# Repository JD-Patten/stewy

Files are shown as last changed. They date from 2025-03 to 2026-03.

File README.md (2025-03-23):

# Stewy

Stewy is a Stewart platform designed as an educational tool. It is capable of moving its top plate around with 6 degrees of freedom and using its arms to lift its base for walking around.

Currently, the code in this repository is working, but needs to be cleaned up and better documented. These improvements will be completed by the end of Stewy's Kickstarter campaign. Please check the kickstarter page [here](https://www.kickstarter.com/projects/jdrobotics/stewy-learn-robotics-with-this-open-source-platform) for an overview and updates on the project.

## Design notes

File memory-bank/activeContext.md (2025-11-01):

# Active Context: Stewy

## Current Work Focus

### Primary Goal: Polish and Expand Core Features
With core motion, communication, and sensor integration complete, focus on refinement, documentation, and advanced behaviors. Collision avoidance is now fully operational, marking a major milestone.

## Recent Changes

### Collision Avoidance Implementation ✅
- **What Changed**: Added _collisionOffsetMagnitude scalar ramping on distance <5cm, _collisionOffsets Pose for translation (+X cos20°, -Z sin20° body-frame)
- **Integration**: Sums with _integratedOffsets in update(), resets on trajectories, _currentPose synced to offsetted pose
- **User Tweaks**: Fixed 150mm target, +X flip for sensor orientation, 5cm threshold (cm units)
- **Files Modified**: controller.h/cpp (members, updateSensorState(), update())
- **Tested**: Triggering, ramping, joystick compatibility, pose adjustment
- **Pattern**: Velocity-based accumulation like joystick, modular Pose summing

### Joystick Pose Control Completion ✅
- **What Changed**: Full JOYSTICK_X/Y/Z modes with DOF mapping, IK-validated _integratedOffsets (Pose)
- **Features**: Velocity deltas, mode-specific trans/rot pairs, reset on trajectory
- **Files Modified**: controller.cpp (updateSensorState())
- **Tested**: Axis control, validation skips invalid, smooth nudging

### Communication Refactoring ✅
- **

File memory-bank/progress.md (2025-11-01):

# Progress: Stewy

## What Works ✅

### Core Functionality (Fully Operational)

#### 1. Inverse Kinematics System
- **Status**: Production-ready
- **Capabilities**:
  - Converts any valid 6-DOF pose to servo angles
  - Validates solutions before returning
  - Handles error conditions gracefully
  - Precomputed geometry for efficiency
- **Tested**: Extensively, handles edge cases
- **Performance**: <1ms solve time

#### 2. Trajectory Planning & Control
- **Status**: Production-ready
- **Capabilities**:
  - Smooth motion between poses using 3rd order polynomials
  - Respects acceleration limits (translation & rotation)
  - Continuous trajectory evaluation
  - Automatic duration minimization
- **Tested**: Various poses, speeds, accelerations
- **Reference**: Based on Modern Robotics textbook

#### 3. Walking Pattern (Forward/Left/Right)
- **Status**: Production-ready
- **Capabilities**:
  - Genetic algorithm-optimized gait
  - Three directions: forward, left, right (left is more backwards left and right more backwards right)
  - Variable speed control
  - Smooth transitions (fade-in, mirroring)
  - Adjustable speed multiplier
- **Tested**: All directions, various speeds
- **Known Limitation**: No true backward (use negative speed)
- **Recent Fix**: Direction inversion corrected by negating speed parameter (genetic algorithm pattern inherently moves backward)

#### 4. Communication Layer
- **Status**: Production-ready
- **Capabilities**:
  - WiFi Access Point (no internet needed)
  - HTTP REST API for commands
  - UDP server for real-time sensor data
  - mDNS for easy connection (robot.local)
  - Callback-based architecture
- **Tested**: Web control, UDP packets from head
- **Reliability**: Stable, handles packet loss

#### 5. Web Interface
- **Status**: Production-ready
- **Capabilities**:
  - Pose control with 6-DOF input
  - Walking control (3 directions + speed)
  - Servo offset calibration
  - Acceleration limit tuning
  - Three-view toggle (control/settings/poses)
  - Mobile-responsive
- **Tested**: Multiple devices, browsers
- **Build Process**: Python script combines HTML/CSS/JS

#### 6. Servo Management
- **Status**: Production-ready
- **Capabilities**:
  - 6 independent PWM channels
  - Angle offset calibration per servo
  - Software angle limits (±80°)
  - Proper sign convention for mirrored servos
  - Interpolation to reduce jitter
- **Tested**: All servos, full range of motion
- **Calibration**: Per-robot tuning supported

#### 7. Joystick Pose Control
- **Status**: Fully implemented
- **Capabilities**:
  - JOYSTICK_X/Y/Z modes for translation/rotation DOFs
  - Velocity-based accumulation in _integratedOffsets (Pose)
  - IK validation before committing offsets
  - Sums with goal pose for physical movement
  - Mode cycling via button click
- **Tested**: Axis mapping, validation, offset application
- **Integration**: Works with collision avoidance offsets

#### 8. Collision Avoidance
- **Status**: Fully implemented and tested
- **Capabilities**:
  - Scalar magnitude (_collisionOffsetMagnitude) ramps at 50mm/s when distance <5cm (fixed 150mm target)
  - Pose offset (_collisionOffsets) as translation: magnitude * cos20° in +X, -magnitude * sin20° in Z (body-frame, zero rotation)
  - Sums with joystick offsets in update()
  - Resets on new trajectories
  - Current pose updated to include offsets for sync
- **Tested**: Triggering, ramping, pose adjustment, compatibility with joystick
- **User Adjustments**: Threshold to 5cm (sensor in cm), +X flip for sensor facing -X, fixed target (from linear)

## What's Left to Build 🚧

### High Priority (Current Sprint)

#### 1. Head Firmware Integration
- **Status**: 50% complete (exists but not in repo)
- **What Works**:
  - Head firmware functional on ESP32-C3
  - Reads distance and joystick
  - Sends UDP packets
- **What's Missing**:
  - Add to this repository
  - Documentation
  - Pin assignment diagram
  - Calibration instructions
- **Complexity**: Low (mostly documentation)
- **Estimate**: 2-3 days

### Medium Priority (Next Sprint)

#### 2. Code Documentation & Cleanup
- **Status**: 40% complete
- **What Exists**:
  - Function comments in key areas
  - Basic README
  - Memory bank documentation
- **What's Needed**:
  - Comprehensive inline comments
  - API documentation
  - Build/setup guide
  - Troubleshooting guide
  - Example code/tutorials
- **Complexity**: Low but time-consuming
- **Estimate**: 2 weeks

#### 3. Configuration Persistence
- **Status**: 0% complete (not started)
- **Requirements**:
  - Save servo offsets to EEPROM/NVS
  - Save acceleration limits
  - Save joystick calibration
  - Load on startup
- **Complexity**: Low
- **Estimate**: 3-4 days
- **Value**: High (no recalibration needed)

#### 4. OTA Firmware Updates
- **Status**: 0% complete (not started)
- **Requirements**:
  - Web-based firmware upload
  - Safe bootloader fallback
  - Version management
- **Complexity**: Medium-High
- **Estimate**: 1-2 weeks
- **Value**: High for users

### Low Priority (Future Enhancements)

#### 5. Additional Walking Patterns
- **Status**: Framework exists, no additional patterns
- **Ideas**:
  - Side-stepping gait
  - Rotating in place
  - Backward walking (true, not reversed forward)
  - Climbing gait
- **Complexity**: Medium (optimization needed)
- **Estimate**: 1 week per pattern
- **Value**: Medium (nice-to-have)

#### 6. Advanced Behaviors
- **Status**: 0% complete (conceptual)
- **Ideas**:
  - Object tracking (using distance sensor)
  - Dance sequences
  - Balancing challenges
  - Interactive games
- **Complexity**: High
- **Estimate**: Variable
- **Value**: High for engagement

#### 7. Mobile App
- **Status**: 0% complete (not planned yet)
- **Alternative**: Current web interface works on mobile
- **Potential Features**:
  - Better joystick emulation
  - Gesture control
  - Saved pose sequences
  - Robot status display
- **Complexity**: High
- **Estimate**: 4-6 weeks
- **Value**: Medium

## Current Status Summary

### Overall Project Completion: ~85%

**Core Platform**: 100% ✅
- Kinematics

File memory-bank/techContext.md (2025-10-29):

# Technical Context: Stewy

## Technology Stack

### Hardware Platform

#### Body Microcontroller
- **Model**: Waveshare ESP32-S3-Nano
- **Processor**: Dual-core Xtensa LX7 @ 240MHz
- **RAM**: 512KB SRAM
- **Flash**: 8MB
- **WiFi**: 802.11 b/g/n (2.4 GHz)
- **GPIO**: Sufficient for 6 PWM channels + peripherals

#### Head Microcontroller
- **Model**: ESP32-C3 Supermini
- **Processor**: RISC-V single-core @ 160MHz
- **RAM**: 400KB SRAM
- **Flash**: 4MB
- **WiFi**: 802.11 b/g/n (2.4 GHz)
- **Purpose**: Lightweight sensor reading and UDP transmission

#### Actuators
- **Type**: 9g metal gear servo motors
- **Quantity**: 6
- **Control**: PWM (50Hz standard)
- **Range**: 0-180° (software limited to ±80° from neutral)
- **Pins**: GPIO 3, 2, 1, 18, 17, 10 (body)

#### Sensors (Head)
- **HC-SR04 Ultrasonic Distance Sensor**
  - Range: 2cm - 400cm
  - Trigger/Echo pins on ESP32-C3
  - Purpose: Obstacle detection
  
- **KY-023 Dual-Axis Joystick**
  - 2x Analog outputs (ADC)
  - 1x Digital button
  - Center values: X=2160, Y=2200 (needs calibration)
  - Deadzone: ±25 units

### Software Stack

#### Development Framework
- **Core**: Arduino Framework
- **Platform**: PlatformIO or Arduino IDE
- **Language**: C++ (C++11 minimum)
- **Build System**: Arduino build chain

#### Key Libraries

##### ESP32Servo
- **Purpose**: PWM servo control on ESP32
- **Features**: 
  - Multiple timer allocation
  - Microsecond pulse width control
  - Configurable min/max pulse (500-2500μs)
- **Usage**: 
  ```cpp
  ESP32PWM::allocateTimer(0-3);  // Allocate 4 timers
  servo.setPeriodHertz(50);
  servo.attach(pin, 500, 2500);
  ```

##### ArduinoEigenDense
- **Purpose**: Linear algebra for IK calculations
- **Features**:
  - Matrix operations
  - Rotation matrices (AngleAxis)
  - Vector math
- **Size Impact**: ~50KB of flash
- **Performance**: Optimized for embedded
- **Usage**:
  ```cpp
  Matrix3d rotation = AngleAxisd(angle, Vector3d::UnitZ()).toRotationMatrix();
  Vector3d result = rotation * point;
  ```

##### WiFi (ESP32 Core)
- **Mode**: Access Point (softAP)
- **Features**:
  - DHCP server built-in
  - WPA2 security
  - No internet connectivity needed
- **Configuration**:
  ```cpp
  WiFi.softAP(ssid, password);
  IPAddress ip = WiFi.softAPIP();
  ```

##### WebServer (ESP32 Core)
- **Purpose**: HTTP REST API
- **Features**:
  - Route handling
  - GET parameter parsing
  - Static content serving
- **Limitations**: Single-threaded, blocking

##### WiFiUDP (ESP32 Core)
- **Purpose**: Real-time sensor data
- **Port**: 4210
- **Packet Size**: 6 bytes (JoystickPacket struct)
- **Performance**: ~10-50ms latency

##### ESPmDNS (ESP32 Core)
- **Purpose**: DNS-SD for easier connection
- **Hostname**: `robot.local`
- **Benefit**: Users don't need to remember IP address

### File Organization

```
stewy/
├── stewy.ino                    # Main entry point
├── controller.h / .cpp          # Motion control
├── inverse_kinematics.h / .cpp  # IK solver
├── walking_pattern.h / .cpp     # Gait generation
├── communication.h / .cpp       # WiFi/HTTP/UDP
├── user_interface.h             # Embedded HTML/CSS/JS
├── README.md                    # Project overview
├── LICENSE                      # Open source license
├── custom_instructions.clinerules # Cline memory bank config
├── CAD/                         # 3D printable parts
│   ├── Stewy Arm Left.step
│   ├── Stewy Arm Right.step
│   ├── Stewy Base Bottom.step
│   ├── Stewy Base top.step
│   └── Stewy Top Plate.step
├── web_interface/               # Web UI development
│   ├── index.html
│   ├── styles.css
│   ├── script.js
│   └── combine.py              # Build tool for user_interface.h
└── memory-bank/                # Cline context (this documentation)
    ├── projectbrief.md
    ├── productContext.md
    ├── systemPatterns.md
    ├── techContext.md
    ├── activeContext.md
    └── progress.md
```

## Development Setup

### Required Tools
1. **Arduino IDE** (v2.0+) OR **PlatformIO** (recommended)
2. **USB Cable** (USB-C for ESP32-S3-Nano)
3. **Serial Monitor** (for debugging)
4. **Python 3** (for web interface build script)

### Board Setup (Arduino IDE)
1. Install ESP32 board package:
   - URL: `https://raw.githubusercontent.com/espressif/arduino-esp32/gh-pages/package_esp32_index.json`
2. Select Board: "ESP32S3 Dev Module" (for body)
3. Select Port: Appropriate COM/tty port

### Library Installation
```
Required Libraries (Arduino Library Manager):
- ESP32Servo (by Kevin Harrington)
- ArduinoEigen (search "Eigen")

Built-in (no install needed):
- WiFi
- WebServer
- WiFiUDP
- ESPmDNS
```

### Build Process

#### For Body Firmware
1. Open `stewy.ino` in IDE
2. Select ESP32-S3 board
3. Compile and upload
4. Monitor serial output for IP address

#### For Web Interface
```bash
cd web_interface/
python combine.py
# This generates user_interface.h from index.html, styles.css, script.js
```

### Debugging Workflow

#### Serial Debugging
```cpp
Serial.begin(115200);
Serial.println("Debug message");
Serial.print("Value: "); Serial.println(value);
```

#### WiFi Connection Testing
1. Connect device to "stewyAP" (password: stewy123)
2. Navigate to `http://192.168.4.1` or `http://robot.local`
3. Check browser console for JavaScript errors

#### Servo Calibration
1. Set all offsets to 0
2. Command neutral pose (0

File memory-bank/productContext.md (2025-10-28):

# Product Context: Stewy

## Why This Project Exists

### Problem Statement
Robotics education often faces barriers:
- **Expensive platforms**: Industrial-grade robots cost thousands
- **Oversimplified kits**: Many educational robots don't teach real robotics concepts
- **Complex theory**: Inverse kinematics and control systems seem inaccessible
- **Limited hands-on experience**: Students learn theory but struggle with implementation

### Solution: Stewy
An affordable, approachable platform that teaches real robotics without oversimplification. Users build, program, and experiment with a robot that uses the same mathematical foundations as industrial robots.

## How It Works

### Core Concept: Stewart Platform
A Stewart platform is a parallel robot with 6 legs connecting a base to a top plate. By controlling the leg lengths (via servo angles), the platform achieves 6-DOF motion. Stewy uses this mechanism both for pose control AND walking.

### User Experience Flow

#### 1. Assembly & Setup
- Users 3D print mechanical parts from provided CAD files
- Assemble with kit-provided electronics
- Flash firmware to ESP32 microcontrollers
- Connect to WiFi access point hosted by robot

#### 2. Initial Calibration
- Web interface provides servo offset adjustment
- Users tune each servo to achieve neutral pose
- Set acceleration limits for smooth motion

#### 3. Pose Control (Primary Mode)
- **Web Interface**: 6 input fields (x, y, z, roll, pitch, yaw)
- **Joystick Control** (planned): Physical joystick controls each axis
- Real-time trajectory planning creates smooth motion
- Visual feedback through robot movement

#### 4. Walking Mode
- Three-direction walking: forward, left, right
- Hexagon-shaped buttons on web interface
- Speed multiplier for variable walking speed
- Genetic algorithm-optimized gait pattern

#### 5. Autonomous Behavior (Planned)
- Distance sensor detects obstacles
- Robot retracts head and walks backward
- Demonstrates basic reactive behavior

### Control Modes
The robot cycles through 5 modes via joystick button click:
1. **STANDARD**: Web interface control only
2. **JOYSTICK_X**: Joystick controls X translation
3. **JOYSTICK_Y**: Joystick controls Y translation  
4. **JOYSTICK_Z**: Joystick controls Z (height)
5. **JOYSTICK_WALK**: Joystick controls walking direction/speed

## Educational Value

### Concepts Taught

#### Beginner Level
- Basic embedded programming (Arduino framework)
- Servo motor control
- WiFi communication
- Web interface development

#### Intermediate Level
- Inverse kinematics mathematics
- Coordinate frame transformations
- PID control and trajectory planning
- Sensor integration and filtering

#### Advanced Level
- Multi-variable optimization (walking pattern)
- Parallel mechanism analysis
- Real-time control systems
- Custom behavior development

### Learning Progression
1. **Week 1-2**: Assembly, basic pose control
2. **Week 3-4**: Understanding IK solver, experimenting with poses
3. **Week 5-6**: Walking patterns, gait analysis
4. **Week 7+**: Custom features, behavior programming

## User Interaction Design

### Web Interface
- **Simple and Clean**: Large buttons, clear labels
- **Three Views**:
  - Control view (pose/walking)
  - Settings view (offsets, accelerations)
  - Pose library (saved positions)
- **Real-time**: Immediate response to commands
- **Mobile-friendly**: Works on phones/tablets

### Physical Remote (Head)
- **Ergonomic**: Designed to be held in hand
- **Tactile Feedback**: Physical joystick for precise control
- **Dual Purpose**: Mounts on body or used as remote
- **Wireless**: No tethering during operation

## Success Criteria

### For Users
- Successfully build and calibrate robot
- Understand inverse kinematics fundamentals
- Create custom poses and walking sequences
- Extend with own code modifications

### For Project
- Clear, comprehensive documentation
- Active community of builders
- Educational institution adoption
- Sustainable through kit sales

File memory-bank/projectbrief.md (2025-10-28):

# Project Brief: Stewy

## Project Overview
Stewy is an educational Stewart platform robot designed to teach robotics concepts at multiple skill levels. The robot features a hexapod-like body with 6 degrees of freedom (6-DOF) for pose control and walking locomotion capabilities.

## Core Mission
Create an accessible, open-source robotics learning platform that teaches:
- Inverse kinematics and forward kinematics
- Control systems and trajectory planning
- Embedded programming on ESP32 microcontrollers
- Real-time sensor integration
- WiFi communication protocols

## Hardware Architecture

### Body (Stewart Platform)
- **Microcontroller**: Waveshare ESP32-S3-Nano
- **Actuators**: 6x 9g metal gear servo motors
- **Mechanical**: Stewart platform configuration with 6-DOF top plate
- **Purpose**: Main control unit, executes motion control

### Head (Sensor Unit - Detachable)
- **Microcontroller**: ESP32-C3 Supermini
- **Sensors**:
  - HC-SR04 ultrasonic distance sensor
  - KY-023 dual-axis joystick module
- **Purpose**: Sensor input, acts as mounted head OR handheld remote
- **Communication**: One-way WiFi/UDP to body (head → body only)

### CAD Files
- 3D printable parts for user fabrication
- Located in `/CAD/` directory
- Users can modify designs for custom builds

## Business Model
- **Original Plan**: Kickstarter campaign (failed)
- **Current Plan**: Direct sales model
- **Product Format**: Kits with all electronic/mechanical components
- **Software**: Fully open-source

## Target Audience
Multi-level educational tool:
- **Beginners**: Learn basic robotics and programming concepts
- **Intermediate**: Understand kinematics and control theory
- **Advanced**: Extend with custom walking patterns, new features

## Key Features
1. **6-DOF Pose Control**: Full position (x,y,z) and orientation (roll,pitch,yaw)
2. **Walking Locomotion**: Tripod gait for three directions (forward, left, right)
3. **Dual Control Modes**:
   - Web interface for pose/walking control
   - Physical joystick on detachable head/remote
4. **Autonomous Behaviors**: Collision avoidance using distance sensor
5. **Extensible Design**: Framework for additional walking patterns

## Project Goals
- Code cleanup and documentation for public release
- Complete head-body integration
- Implement full joystick control for all 6 pose axes
- Collision avoidance behavior
- Educational materials and tutorials

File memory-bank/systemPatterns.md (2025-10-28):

# System Patterns: Stewy

## System Architecture Overview

```
┌─────────────────────────────────────────────────────────┐
│                    HEAD (ESP32-C3)                      │
│  ┌──────────────┐  ┌──────────────┐                    │
│  │  HC-SR04     │  │   KY-023     │                    │
│  │  Distance    │  │   Joystick   │                    │
│  └──────┬───────┘  └──────┬───────┘                    │
│         │                  │                             │
│         └────────┬─────────┘                            │
│                  │                                       │
│         ┌────────▼─────────┐                           │
│         │  Head Firmware   │                           │
│         │  (Separate .ino) │                           │
│         └────────┬─────────┘                           │
│                  │                                       │
│                  │ UDP Packets (One-way)                │
└──────────────────┼───────────────────────────────────┘
                   │ WiFi
                   ▼
┌─────────────────────────────────────────────────────────┐
│              BODY (ESP32-S3-Nano)                       │
│                                                          │
│  ┌──────────────────────────────────────────────────┐  │
│  │            Communication Layer                    │  │
│  │  ┌────────────┐  ┌────────────┐  ┌────────────┐  │  │
│  │  │   WiFi AP  │  │ HTTP Server│  │ UDP Server │  │  │
│  │  │   + mDNS   │  │   (REST)   │  │  (Sensors) │  │  │
│  │  └─────┬──────┘  └─────┬──────┘  └─────┬──────┘  │  │
│  └────────┼───────────────┼───────────────┼─────────┘  │
│           │               │               │             │
│  ┌────────▼───────────────▼───────────────▼─────────┐  │
│  │              Main Loop (stewy.ino)               │  │
│  │  - Registers callbacks for HTTP/UDP              │  │
│  │  - Routes commands to Controller                 │  │
│  └────────┬─────────────────────────────────────────┘  │
│           │                                             │
│  ┌────────▼─────────────────────────────────────────┐  │
│  │              Controller                           │  │
│  │  - Trajectory Planning                            │  │
│  │  - Mode Management (5 modes)                      │  │
│  │  - Sensor State Processing                        │  │
│  │  - Walking/Pose Coordination                      │  │
│  └────────┬──────────────────┬──────────────────────┘  │
│           │                  │                          │
│  ┌────────▼──────────┐  ┌───▼────────────────────┐    │
│  │   IK Solver       │  │  Walking Pattern       │    │
│  │  - Pose → Angles  │  │  - Sin Wave Generator  │    │
│  │  - Eigen Math     │  │  - Gait Mirroring      │    │
│  └────────┬──────────┘  └───┬────────────────────┘    │
│           │                  │                          │
│           └────────┬─────────┘                          │
│                    │                                     │
│           ┌────────▼──────────┐                         │
│           │  Servo Manager    │                         │
│           │  - 6 PWM Channels │                         │
│           │  - Angle Offsets  │                         │
│           │  - Limits/Clamp   │                         │
│           └────────┬──────────┘                         │
│                    │                                     │
│  ┌─────────────────▼──────────────────────────────┐    │
│  │         6x Servo Motors (Hardware)              │    │
│  └─────────────────────────────────────────────────┘    │
└─────────────────────────────────────────────────────────┘
```

## Key Components

### 1. Inverse Kinematics Solver (`IKSolver` class)

**Purpose**: Convert desired end-effector pose (x,y,z,roll,pitch,yaw) to 6 servo angles

**Algorithm**:
```
For each of 6 legs:
1. Apply rotation matrix to top plate connection point
2. Add translation to get world coordinates
3. Transform to servo's local frame
4. Solve 2-link inverse kinematics equation
5. Convert from radians to degrees
```

**Key Design Decisions**:
- Uses Eigen library for matrix operations
- Precomputes connection points and rotation matrices in constructor
- Returns `IKResult` struct with success flag and error messages
- Supports arbitrary Stewart platform geometry via constructor parameters

**Critical Parameters** (in stewy.ino):
- `servoArmLength`: 50mm (first link)
- `arm2Length`: 100mm (second link)
- `servoOffset1/2`: Base plate arm spacing
- `topPlateOffset1/2`: Top plate arm spacing
- `draftAngle`: 15° (servo tilt angle)

### 2. Controller (`Controller` class)

**Purpose**: Orchestrate all motion control, sensor processing, mode management

**State Machine**:
```
Modes (cycle on joystick click):
STANDARD → JOYSTICK_X → JOYSTICK_Y → JOYSTICK_Z → JOYSTICK_WALK → (back to STANDARD)
```

**Key Responsibilities**:
1. **Trajectory Planning**: 3rd order polynomial time scaling (Modern Robotics textbook)
2. **Mode Management**: Handle 5 different control modes
3. **Sensor Processing**: Joystick deadzone, centering, direction detection
4. **Walking Coordination**: Fade-in transitions, pattern mirroring
5. **Servo Management**: Apply offsets, enforce limits

**Important Methods**:
- `update()`: Main control loop, called every iteration
- `setGoalPose()`: Validates and initiates new pose trajectory
- `startWalking()`: Transitions from pose control to walking
- `updateSensorState()`: Processes joystick/distance sensor data

**Trajectory Planning**:
- Minimizes duration while respecting acceleration limits
- Separate limits for translation (`maxAcceleration`) and rotation (`maxAngularAcceleration`)
- Uses s-curve (3rd order polynomial) for smooth motion
- Formula: `s(t) = 3t²/T² - 2t³/T³` where T is duration

### 3. Walking Pattern (`WalkingPattern1` class)

**Algorithm**: Genetic algorithm-optimized sin wave composition

**IMPORTANT - Genetic Algorithm Origin**:
- The sin wave parameters were generated by a genetic algorithm that optimized ONLY for distance traveled
- The algorithm did NOT optimize for direction of travel
- The resulting pattern inherently moves the robot BACKWARD by default
- To correct this, the speed parameter is negated at the start of `getAngles()`: `speed = -speed;`
- This reverses the animation playback, making forward motion actually move forward
- The mirroring pattern (explained below) keeps the robot walking straight, but does not guarantee forward motion
- Future walking patterns from genetic algorithms may also need velocity negation if they move backward

**6 Sin Waves** (one per DOF):
```cpp
x:     amplitude=10.952, period=1.0, offset=11.508,  phase=0.54
y:     amplitude=10.476, period=2.0, offset=-9.921,  phase=0.365
z:     amplitude=25.238, period=1.0, offset=89.206,  phase=0.476
roll:  amplitude=19.048, period=1.0, offset=-4.048,  phase=0.603
pitch: amplitude=2.54,   period=1.0, offset=0.714,   phase=0.286
yaw:   amplitude=3.81,   period=1.0, offset=-13.095, phase=0.952
```

**Gait Pattern**:
```
Full Cycle: 1.4s (adjustable with speed multiplier)
├─ Phase 1 (0.5s): Forward motion using sin waves
├─ Transition 1 (0.1s): Linear interpolation
├─ Phase 2 (0.5s): Mirrored motion (swap legs, negate angles)
└─ Transition 2 (0.1s): Linear interpolation back
```

**Mirroring Pattern**: `[1,2,3,4,5,6] → [-4,-3,-2,-1,-6,-5]`

**Direction Mapping**:
- Forward: Rotate leg assignment by 2 positions
- Left: Rotate leg assignment by 4 positions
- Right: No rotation (base pattern)

### 4. Communication Layer

**WiFi Configuration**:
- Access Point mode (no internet required)
- SSID: "stewyAP", Password: "stewy123"
- mDNS: `robot.local` (for easier connection)
- UDP Port: 4210 (sensor data)
- HTTP Port: 80 (web interface)

**Protocol Design**:
- **HTTP**: Command-based REST API
  - `/pose1?params=x,y,z,roll,pitch,yaw`
  - `/walk?params=speed,direction`
  - `/setOffsets?params=s1,s2,s3,s4,s5,s6`
- **UDP**: Real-time sensor packets (6 bytes)
  ```
  struct JoystickPacket {
    int16_t joyX;      // 2 bytes
    int16_t joyY;      // 2 bytes
    uint8_t clicked;   // 1 byte
    uint8_t padding;   // 1 byte
    uint16_t distance; // 2 bytes
  }
  ```

**Callback Pattern**:
```cpp
// Main program registers handlers
onHttpCommand(httpCommandHandler);
onUdpPacket(udpPacketHandler);

// Communication module calls them when data arrives
```

## Critical Design Patterns

### 1. Servo Angle Sign Convention
**IMPORTANT**: Odd-numbered servos (1,3,5) have inverted angles
```cpp
// When publishing to servos:
for (i = 0; i < 6; i++) {
    checkAngle = (i % 2 == 0) ? -angles[i] : angles[i];
    // Apply offset, limits...
    publishAngle = (i % 2 == 0) ? -constrainedAngle : constrainedAngle;
    servos[i].write(publishAngle + 90);  // 90° is neutral
}
```

### 2. Joystick Direction Detection
Uses **dot product** with unit vectors to find best match:
```cpp
directions = {
    "forward": (0, 1.0),
    "left": (0.866, -0.5),     // 120°
    "right": (-0.866, -0.5),   // 240°
    // ... etc
}

// Find direction with largest dot product
dot = joyX * dirX + joyY * dirY
```

### 3. Walking Fade-In
Prevents jarring transitions when starting to walk:
```cpp
fadeInDuration = 0.2 / abs(speed);
fadeInPercent = min(timeSinceStart / fadeInDuration, 1.0);
finalAngle = walkingAngle * fadeInPercent + startAngle * (1 - fadeInPercent);
```

### 4. Pose Validation
Always validate IK solution before accepting new goal:
```cpp
IKResult result = ikSolver.solveInverseKinematics(goalPose);
if (!result.success) {
    // Reject pose, keep current goal
    return;
}
```

## Data Flow Examples

### Web Command → Servo Motion
```
1. User clicks "Set Pose" on web interface
2. JavaScript sends HTTP GET: /pose1?params=0,0,110,0,0,0
3. Communication module parses request
4. Calls registered httpCommandHandler()
5. Handler parses params into Pose object
6. controller.setGoalPose(pose)
7. Controller validates with IK solver
8. Creates trajectory from current → goal
9. Main loop calls controller.update()
10. Controller follows trajectory, solves IK each step
11. Publishes angles to servos
```

### Joystick → Walking
```
1. Head firmware reads joystick (joyX, joyY, clicked)
2. Sends UDP packet to body
3. Communication module receives packet
4. Calls registered udpPacketHandler()
5. Handler calls controller.updateSensorState()
6. Controller detects mode = JOYSTICK_WALK
7. Computes direction via dot product
8. Calls startWalking(direction, speed)
9. Main loop calls controller.update()
10. Controller calls walkingPattern.getAngles()
11. Publishes angles to servos
```

## Performance Characteristics

- **Control Loop Rate**: ~100Hz (limited by servo update rate)
- **Trajectory Resolution**: Continuous (evaluated each loop)
- **Walking Cycle**: 1.4s at speed=1.0 (variable with speed multiplier)
- **IK Solve Time**: <1ms per pose
- **WiFi Latency**: ~10-50ms (UDP packets)
- **Servo Update Rate**: 50Hz (standard PWM frequency)

## Extension Points

### Adding New Walking Patterns
1. Create new class inheriting pattern interface
2. Implement `getAngles(direction, speed)` method
3. Initialize in Controller constructor
4. Switch between patterns via mode or command

### Adding Control Modes
1. Add enum value to `ControlMode`
2. Increment modulo in mode cycling logic
3. Implement behavior in `updateSensorState()` or `update()`

### Custom Commands
1. Add route handler in stewy.ino `httpCommandHandler()`
2. Parse parameters from URL string
3. Call appropriate Controller methods

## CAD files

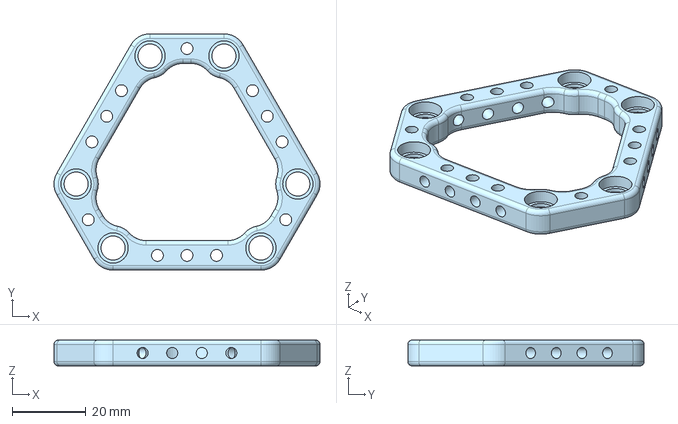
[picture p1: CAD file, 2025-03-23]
CAD/Stewy Top Plate.step
72.0 x 64.0 x 7.00 mm

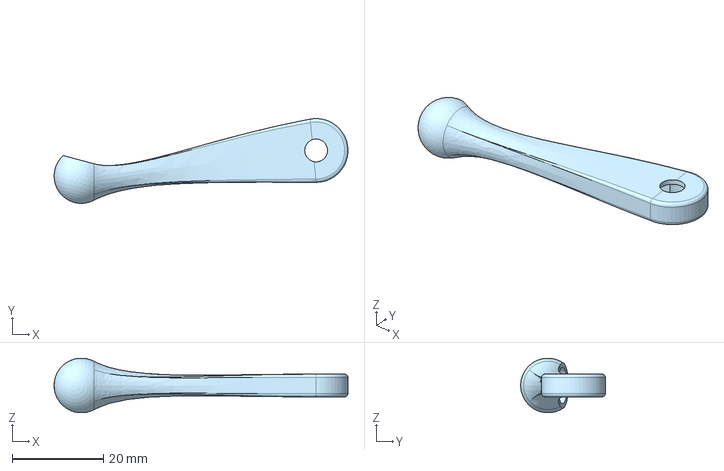
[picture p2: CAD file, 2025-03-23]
CAD/Stewy Arm Left.step
64.5 x 18.6 x 12.0 mm

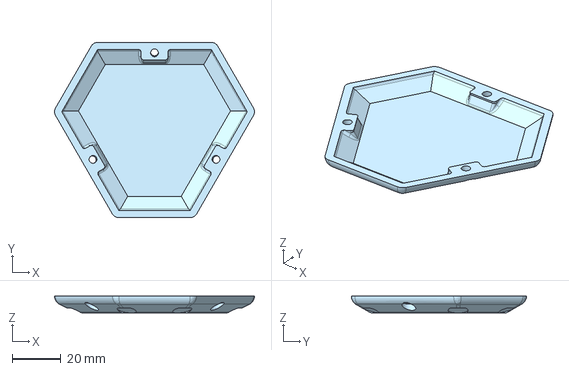
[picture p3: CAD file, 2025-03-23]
CAD/Stewy Base Bottom.step
82.5 x 72.3 x 7.00 mm

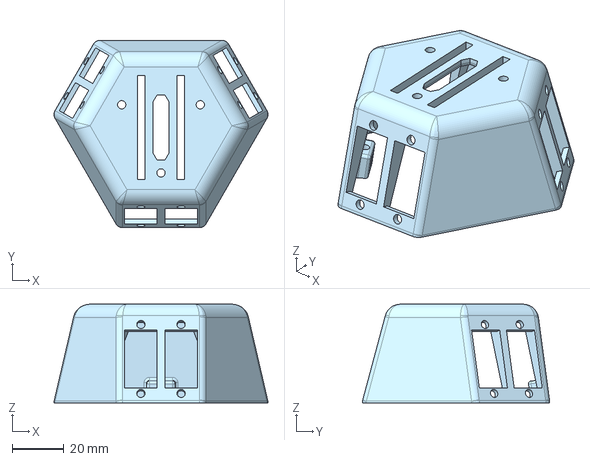
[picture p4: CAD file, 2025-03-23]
CAD/Stewy Base top.step
82.5 x 72.3 x 38.0 mm

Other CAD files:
CAD/Stewy Arm Right.step

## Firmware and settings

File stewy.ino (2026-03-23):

#include "inverse_kinematics.h"
#include "controller.h"
#include <ESP32Servo.h>
#include "communication.h"   

// change these to fix mechanical offsets in the arms
vector<float> servoOffsets = {-5, 10, 5, 0, 0, 10};  
float deadzone = 100;

#define LED_BUILTIN 48   

// Set these to your desired credentials.
const char *ssid = "stewyAP";
const char *password = "stewy123";

// Servo setup
Servo servos[6];
int servoPins[6] = {3,2,1,18,17,10};

// Create IK solver instance
IKSolver ikSolver(
    50,     // servoArmLength
    100,    // arm2Length
    73,     // servoOffset1
    15.5,   // servoOffset2
    0,     // servoZOffset
    15,     // draftAngle
    40,     // topPlateOffset1
    20,     // topPlateOffset2
    -10     // topPlateZOffset
);

float maxAcceleration = 10;
float maxRotationalAcceleration = 10;
Controller controller(servoPins, ikSolver, maxAcceleration, maxRotationalAcceleration );  

bool isProcessingRequest = false;  // kept for compatibility (not used by comms here)

//
// Simple HTTP command handler that just prints path and params.
// Replace with your full parser later (this is intentionally minimal).
//
void httpCommandHandler(const String& path, const String& params) {
  Serial.print("HTTP command received. Path: ");
  Serial.print(path);
  Serial.print("  Params: ");
  Serial.println(params);

  if (path == "/pose1") {
    Pose poseToSet;
    if (poseToSet.fromString(params)) {
      controller.setGoalPose(poseToSet);
    } else {
      Serial.println("Invalid pose format in params");
    }
  } else if (path == "/setOffsets") {
    Serial.println("Handling servo offsets update");
    vector<float> newOffsets(6, 0.0f);
    int count = 0;
    int start = 0;
    String paramStr = params;
    bool valid = true;
    for (int i = 0; i < 6; i++) {
      int comma = paramStr.indexOf(',', start);
      if (comma == -1) {
        comma = paramStr.length();
        if (i < 5) valid = false;  // Need 6 values
      }
      String valStr = paramStr.substring(start, comma);
      valStr.trim();  // Remove whitespace
      newOffsets[i] = valStr.toFloat();
      start = (comma < paramStr.length() && i < 5) ? comma + 1 : -1;
      count++;
    }
    if (valid && count == 6) {
      servoOffsets = newOffsets;
      controller.setOffsets(servoOffsets);
      Serial.println("Offsets updated to:");
      for (int i = 0; i < 6; i++) {
        Serial.print("Servo "); Serial.print(i); Serial.print(": "); Serial.println(newOffsets[i]);
      }
    } else {
      Serial.println("Invalid offsets params: expected exactly 6 comma-separated floats");
    }
 } else if (path == "/setAngles") {
    Serial.println("Setting servo angles");
    vector<float> newAngles(6, 0.0f);
    int count = 0;
    int start = 0;
    String paramStr = params;
    bool valid = true;
    for (int i = 0; i < 6; i++) {
      int comma = paramStr.indexOf(',', start);
      if (comma == -1) {
        comma = paramStr.length();
        if (i < 5) valid = false;  // Need 6 values
      }
      String valStr = paramStr.substring(start, comma);
      valStr.trim();  // Remove whitespace
      newAngles[i] = valStr.toFloat();
      start = (comma < paramStr.length() && i < 5) ? comma + 1 : -1;
      count++;
    }
    if (valid && count == 6) {
      controller.setAngles(newAngles);
      Serial.println("Angles updated to:");
      for (int i = 0; i < 6; i++) {
        Serial.print("Servo "); Serial.print(i); Serial.print(": "); Serial.println(newAngles[i]);
      }
    } else {
      Serial.println("Invalid angles params: expected exactly 6 comma-separated floats");
    }

  } else if (path == "/walk") {
    // Example params: "direction,speedMultiplier"
    int commaIndex = params.indexOf(',');
    if (commaIndex != -1) {
      String speedStr = params.substring(0, commaIndex);
      String direction = params.substring(commaIndex + 1);
      float speedMultiplier = speedStr.toFloat();
      controller.startWalking(direction, speedMultiplier);
      Serial.println("Started walking " + direction + " at speed multiplier " + String(speedMultiplier));
    } else {
      Serial.println("Invalid startWalk params");
    }

  }else if (path == "/setMaxAccel") {
    // Example params: "transAccel,rotAccel"
    int commaIndex = params.indexOf(',');
    if (commaIndex != -1) {
      String transStr = params.substring(0, commaIndex);
      String rotStr = params.substring(commaIndex + 1);
      float transAccel = transStr.toFloat();
      float rotAccel = rotStr.toFloat();
      controller.setAccelerationLimits(transAccel, rotAccel);
      Serial.println("Set max accelerations - Translational: " + String(transAccel) + ", Rotational: " + String(rotAccel));
    } else {
      Serial.println("Invalid setMaxAccel params");
    }
  }
  // Blink built-in LED to indicate request processed 
  digitalWrite(LED_BUILTIN, HIGH);
  delay(10);
  digitalWrite(LED_BUILTIN, LOW);
}

void udpPacketHandler(const JoystickPacket& pkt) {
    // Example: just print the received joystick packet
    Serial.print("UDP Packet - JoyX: "); Serial.print(pkt.joyX);
    Serial.print(" JoyY: "); Serial.print(pkt.joyY);
    Serial.print(" Clicked: "); Serial.print(pkt.clicked);
    Serial.print(" Distance: "); Serial.println(pkt.distance);

    controller.updateSensorState(pkt.distance, pkt.joyX, pkt.joyY, pkt.clicked);
}

void setup() {
  pinMode(LED_BUILTIN, OUTPUT);

  Serial.begin(115200);
  delay(1000);
  Serial.println("Starting up...");
  
  Serial.println();
  Serial.println("Configuring access point...");

  // Start comms (AP, mDNS and HTTP server, UDP etc are handled inside communication.*).
  // wifiSetup will use the SSID/password provided.
  wifiSetup(ssid, password);
  Serial.println("wifiSetup() called");

  // Register generic HTTP command callback so communication module forwards commands here.
  onHttpCommand(httpCommandHandler);
  onUdpPacket(udpPacketHandler);


// Find home position
Pose homePose;

vector<float> targetAngles = {-23, 23, -23, 23, -23, 23};
float zMin = 0, zMax = 300;

while(zMax - zMin > 0.1) {
    float zMid = (zMin + zMax) / 2.0;
    auto result = ikSolver.solveInverseKinematics(Pose(0, 0, zMid, 0, 0, 0));
    
    if(!result.success) {
        zMax = zMid;
        continue;
    }
    
    float maxError = 0;
    for(int i = 0; i < 6; i++) {
        maxError = max(maxError, abs(result.angles[i] - targetAngles[i]));
    }
    
    if(maxError < 0.1) {
        Serial.println("Found homePose: (0,0," + String(zMid) + ",0,0,0) with angles: " + String(result.angles[0]) + ", " + String(result.angles[1]) + ", " + String(result.angles[2]) + ", " + String(result.angles[3]) + ", " + String(result.angles[4]) + ", " + String(result.angles[5]));
        homePose = Pose(0, 0, zMid, 0, 0, 0);
        break;
    }
    
    (result.angles[0] < targetAngles[0]) ? zMin = zMid : zMax = zMid;
}

// start the controller
controller.setOffsets(servoOffsets);
controller.setDeadzone(deadzone);
controller.begin(homePose);
}

void loop() {
  // keep controller running as before
  controller.update();

  // Let communication module handle HTTP/UDP and forward requests to our callback.
  wifiRun();

  // (Optionally) other robot logic can go here
}

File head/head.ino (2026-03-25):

#include <WiFi.h>
#include <WiFiUdp.h>

// ---- Wi-Fi Network Config ----
const char* ssid = "stewyAP";
const char* password = "stewy123";
const IPAddress receiverIP(192, 168, 4, 1);  // AP’s IP (the UDP receiver)
const int receiverPort = 4210;

WiFiUDP udp;

// ---- Joystick Pins ----
#define VRX_PIN     3   // Joystick X
#define VRY_PIN     1   // Joystick Y
#define SWITCH_PIN  0   // Joystick Button

// ---- Ultrasonic Sensor Pins ----
#define TRIG_PIN    4   // HC-SR04 Trig
#define ECHO_PIN    5   // HC-SR04 Echo



// ---- Packet Structure ----
struct JoystickPacket {
  int16_t joyX;
  int16_t joyY;
  uint8_t clicked;
  uint8_t padding;
  uint16_t distance;
};

void setup() {
  Serial.begin(115200);
  delay(500);

  pinMode(SWITCH_PIN, INPUT_PULLUP);
  pinMode(TRIG_PIN, OUTPUT);
  pinMode(ECHO_PIN, INPUT);

  // Connect to Access Point
  WiFi.setSleep(false);
  WiFi.begin(ssid, password);

  Serial.println("Connecting to WiFi...");

  unsigned long start = millis();
  while (WiFi.status() != WL_CONNECTED) {
    if (millis() - start > 10000) {
      Serial.println("\nConnection timeout!");
      return;
    }
    delay(200);
    Serial.print(".");
  }

  Serial.println("\nConnected!");
  Serial.print("IP: ");
  Serial.println(WiFi.localIP());

  udp.begin(4211);
}

uint16_t getDistance() {
  digitalWrite(TRIG_PIN, LOW);
  delayMicroseconds(2);
  digitalWrite(TRIG_PIN, HIGH);
  delayMicroseconds(10);
  digitalWrite(TRIG_PIN, LOW);
  long duration = pulseIn(ECHO_PIN, HIGH, 20000); // 20 ms timeout
  uint16_t distance = duration * 0.034 / 2; // cm
  return constrain(distance, 0, 400);
}

void loop() {

  static unsigned long lastAttempt = 0;

  if (WiFi.status() == WL_DISCONNECTED && millis() - lastAttempt > 3000) {
    Serial.println("Reconnecting...");
    WiFi.begin(ssid, password);
    lastAttempt = millis();
  }

  if (WiFi.status() != WL_CONNECTED) {
    delay(50);
    return;
  }

  JoystickPacket pkt;

  pkt.joyX = analogRead(VRX_PIN);
  pkt.joyY = analogRead(VRY_PIN);
  pkt.clicked = !digitalRead(SWITCH_PIN);
  pkt.distance = getDistance();

  // Send binary UDP packet
  udp.beginPacket(receiverIP, receiverPort);
  udp.write((uint8_t*)&pkt, sizeof(pkt));
  udp.endPacket();

  // Debug print
  Serial.print("Sent: X=");
  Serial.print(pkt.joyX);
  Serial.print(" Y=");
  Serial.print(pkt.joyY);
  Serial.print(" Clicked=");
  Serial.print(pkt.clicked);
  Serial.print(" Distance=");
  Serial.println(pkt.distance);

  delay(50); // 20 Hz update rate
}

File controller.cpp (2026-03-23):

#include "controller.h"

Controller::Controller(int servoPins[6], IKSolver ikSolver, float maxAcceleration, float maxAngularAcceleration)
    : _ikSolver(ikSolver)
    , _servoAngleOffsets(6, 0.0)
    , _servoAngleMin(-80.0)             //degrees
    , _servoAngleMax(80.0)              //degrees
    , _maxAcceleration(maxAcceleration)
    , _maxAngularAcceleration(maxAngularAcceleration)
    , _isWalking(false)
    , _walkingDirection("no direction")
    , _walkingPattern(WalkingPattern1())
    , _speedMultiplier(1.0)
    , _lastCommandedAngles(6, 0.0)
    , _currentMode(STANDARD)
    , _inVelocityMode(false)
    , _lastSensorTime(millis())
    , _deadzone(50)
{
    // Initialize ESP32 PWM
    ESP32PWM::allocateTimer(0);
    ESP32PWM::allocateTimer(1);
    ESP32PWM::allocateTimer(2);
    ESP32PWM::allocateTimer(3);

    // attach servos with proper configuration
    for (int i = 0; i < 6; i++) {
        _servos[i].setPeriodHertz(50);    // Standard 50hz servo
        _servos[i].attach(servoPins[i], 500, 2500);  // Attach servo with min/max pulse widths
    }

    _integratedOffsets = Pose();
}
        
void Controller::begin(const Pose& initialPose) {

    _trajectory._isFinished = true;

    // Servo initialization sequence
    publishToServos(vector<float>{0,0,0,0,0,0});
    delay(300);
    
    // Loop through each servo
    for(int i = 0; i < 6; i++) {
        vector<float> angles = {0,0,0,0,0,0};
        angles[i] = (i % 2 == 0) ? -5 : 5;  // alternate between -5 and 5
        publishToServos(angles);
        delay(100);
        publishToServos(vector<float>{0,0,0,0,0,0});
        delay(50);
    }

    // If a valid initial pose is provided, set it
    // and if not set all servos to angle zero + offsets

    if(_ikSolver.solveInverseKinematics(initialPose).success) {
        _goalPose = initialPose;
        _currentPose = initialPose;
    } else {
        Serial.println("Warning: Initial pose is invalid, setting to zero pose.");
        _currentPose = Pose(0, 0, 0, 0, 0, 0);
        _goalPose = Pose(0, 0, 0, 0, 0, 0);
        publishToServos(vector<float>(6, 0.0));
    }

}

void Controller::publishToServos(const vector<float>& angles) {
    // Debug print for angles being sent to servos
    
    for (int i = 0; i < 6; i++) {
        // For odd servos, check limits on positive value but publish negative
        float checkAngle = (i % 2 == 0) ? -angles[i] : angles[i];

        // Apply offset
        float offsetAngle = checkAngle + _servoAngleOffsets[i];
        
        // Clamp angle between min and max
        float constrainedAngle = min(max(offsetAngle, _servoAngleMin), _servoAngleMax);
        
        // Convert back to publishing direction
        float publishAngle = (i % 2 == 0) ? -constrainedAngle : constrainedAngle;

        // Store the commanded angle (without the 90 degree offset)
        _lastCommandedAngles[i] = angles[i];
        
        _servos[i].write(publishAngle + 90);
    }
}

void Controller::updateSensorState(float raw_distance, float raw_joyX, float raw_joyY, bool raw_joyClick) {
    // update internal sensor states
    _prevJoyClick = _joyClick;
    _joyClick = raw_joyClick;
    _distance = raw_distance;

    // recenter joystick values and apply deadzone
    float xCenter = 2200;
    float yCenter = 2200;

    _joyX = raw_joyX - xCenter;
    if (abs(_joyX) < _deadzone) _joyX = 0;
    _joyY = raw_joyY - yCenter;
    if (abs(_joyY) < _deadzone) _joyY = 0;

    // Shared dt computation for sensor integrations
    unsigned long now = millis();
    float dt = (now - _lastSensorTime) / 1000.0f;
    _lastSensorTime = now;
    if (dt > 0.1f) dt = 0.1f;

    float magnitude = sqrt(_joyX * _joyX + _joyY * _joyY);
    if (magnitude > 2000) magnitude = 2000;


    // unit vectors for seelcting a direction based on joystick position
    // left and right are back left and back right faces of the robot
    vector<pair<String, pair<float, float>>> directions = {
        {"forward", {0 , 1.0}},
        {"left", {0.866025, -0.5}},
        {"right", {-0.866025, -0.5}},
        {"backward", {0 , -1.0}},
        {"forward left", {0.866025, 0.5}},
        {"forward right", {-0.866025, 0.5}}
    };

    // if the joystick was just clicked change the "mode" of the robot
    if (_joyClick && !_prevJoyClick) {
        _currentMode = static_cast<ControlMode>((_currentMode + 1) % 5);
        Serial.println("Control mode: " + getModeString());
        _isWalking = false;  // stop walking when mode changes
    }

    // Set velocity mode based on current mode
    if (_currentMode == JOYSTICK_X || _currentMode == JOYSTICK_Y || _currentMode == JOYSTICK_Z) {
        _inVelocityMode = true;
    } else {
        _inVelocityMode = false;
    }

    float largestDot = 0.0;
    bool flipDirection = false;
    String newWalkingDirection = "none";
    // use the dot product to determine which direction to walk in
    for (auto& dir : directions) {
        float dot = (_joyX * dir.second.first + _joyY * dir.second.second);

        if (dot > largestDot) {
            if (dir.first == "backward") {
                newWalkingDirection = "forward";
                flipDirection = true;
            } else if (dir.first == "forward left") {
                newWalkingDirection = "right";
                flipDirection = true;
            } else if (dir.first == "forward right") {
                newWalkingDirection = "left";
                flipDirection = true;
            } else {
                newWalkingDirection = dir.first;
            }
            largestDot = dot;
            }
        }


    // if in walking mode, send walk command based on joystick position
    if (_currentMode == JOYSTICK_WALK) {

        // now set walking
        if (magnitude > 0) {
            float velocity = largestDot * 1.0 / 2000.0;
            if (flipDirection == true) velocity *= -1.0;

            if (_isWalking && _walkingDirection == newWalkingDirection) {
                // already walking in this direction just update the speed
                _walkingDirection = newWalkingDirection;
                _speedMultiplier = velocity;
            } else{
                _walkingDirection = newWalkingDirection;
                _speedMultiplier = velocity;
                startWalking(_walkingDirection, _speedMultiplier);
                Serial.println("Started walking " + String(_walkingDirection) + " with speed multiplier: " + String(_speedMultiplier));
            }
        } else {
            _isWalking = false;
        }
    }


    // Print-only basic integration test for JOYSTICK_X/Y/Z modes
    if (_inVelocityMode && _trajectory._isFinished) {
        if (dt > 0.0f) {
            // Tuning constants
            const float joy_max = 2000.0f;
            const float max_trans_vel = 70.0f;  // mm/s
            const float max_rot_vel = 50.0f;    // deg/s
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

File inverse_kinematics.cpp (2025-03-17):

#include <ArduinoEigenDense.h>
#include <vector>
#include <cmath>
#include "inverse_kinematics.h"

using namespace Eigen;
using namespace std;

// Constructor definition
IKSolver::IKSolver(float servoArmLength, float arm2Length, float servoOffset1,
                   float servoOffset2, float servoZOffset, float draftAngle, 
                   float topPlateOffset1, float topPlateOffset2, float topPlateZOffset)
    // initialize member variables
    : _servoArmLength(servoArmLength)
    , _arm2Length(arm2Length)

    // compute derived member variables
    , _topPlateArmConnections(computeConnectionPoints(topPlateOffset1, topPlateOffset2, topPlateZOffset))
    , _servoTranslations(computeConnectionPoints(servoOffset1, servoOffset2, servoZOffset))
    , _servoRotations(initializeServoRotations(draftAngle))
{
    // constructor body can be empty since all initialization is done in the list
}

// Function to compute servo or connection point coordinates
vector<Vector3d> IKSolver::computeConnectionPoints(float offset_1, float offset_2, float z_height) {
    float d1 = (1.0 / 6.0) * (offset_1 - offset_2);
    float d2 = (1.0 / 3.0) * (offset_1 - offset_2);
    float c = offset_1 - (2 * d1);
    float radius = sqrt(c * c + d2 * d2 - 2 * c * d2 * cos(M_PI / 3.0));

    // Rotation matrices for 120 and 240 degrees around the Z-axis
    Matrix3d rotate_120 = AngleAxisd(2 * M_PI / 3.0, Vector3d::UnitZ()).toRotationMatrix();
    Matrix3d rotate_240 = AngleAxisd(4 * M_PI / 3.0, Vector3d::UnitZ()).toRotationMatrix();

    // Compute translation vectors
    Vector3d number1(-sqrt(radius * radius - (offset_1 / 2) * (offset_1 / 2)), offset_1 / 2, z_height);
    Vector3d number6(number1.x(), -number1.y(), z_height);
    Vector3d number2 = rotate_240 * number6;
    Vector3d number3 = rotate_240 * number1;
    Vector3d number4 = rotate_120 * number6;
    Vector3d number5 = rotate_120 * number1;

    return {number1, number2, number3, number4, number5, number6};
}

// Function to initialize servo rotations
vector<Matrix3d> IKSolver::initializeServoRotations(float draftAngle) {
    vector<float> zAngles = {-120, -120, 0, 0, 120, 120}; // rotate servo to correct side
    vector<float> xAngles = {0, -180, 0, -180, 0, -180};   // flip every other servo 

    vector<Matrix3d> servoRotations;\
    for (int i = 0; i < 6; ++i) {
        Matrix3d rotation =
            AngleAxisd(xAngles[i] * M_PI / 180.0, Vector3d::UnitX()).toRotationMatrix() *
            AngleAxisd(draftAngle * M_PI / 180.0, Vector3d::UnitY()).toRotationMatrix() *
            AngleAxisd(zAngles[i] * M_PI / 180.0, Vector3d::UnitZ()).toRotationMatrix();

        servoRotations.push_back(rotation);
    }
    return servoRotations;
}

// Function to solve inverse kinematics
IKResult IKSolver::solveInverseKinematics(const Pose& pose) const {
    vector<float> servoAngles(6, 0.0);

    // Convert roll, pitch, and yaw to radians
    float roll = pose.roll * M_PI / 180.0;
    float pitch = pose.pitch * M_PI / 180.0;
    float yaw = pose.yaw * M_PI / 180.0;

    // Compute rotation matrix
    Matrix3d rotationMatrix = 
        AngleAxisd(yaw, Vector3d::UnitZ()).toRotationMatrix() * 
        AngleAxisd(pitch, Vector3d::UnitY()).toRotationMatrix() * 
        AngleAxisd(roll, Vector3d::UnitX()).toRotationMatrix();

    // Solve inverse kinematics for each arm
    for (int i = 0; i < 6; ++i) {
        // Step 1: Apply rotation and translation to end effector connection point
        Vector3d endConnectionPoint = rotationMatrix * _topPlateArmConnections[i];
        endConnectionPoint = endConnectionPoint + Vector3d(pose.x, pose.y, pose.z);

        // Step 2: Transform point to servo frame
        Vector3d pointInServoFrame = _servoRotations[i] * (endConnectionPoint - _servoTranslations[i]);

        // Step 3: Solve inverse kinematics equation for servo angle
        float px = pointInServoFrame.x();
        float py = pointInServoFrame.y();
        float pz = pointInServoFrame.z();
        float l1 = _servoArmLength;
        float l2 = _arm2Length;

        float denominator = -2 * l1 * sqrt(py * py + pz * pz);
        float angle = 0.0;

        if (denominator == 0) {
            return IKResult("Division by zero in IK computation!");
        }

        float acosValue = (l2 * l2 - px * px - py * py - pz * pz - l1 * l1) / denominator;
        if (acosValue > 1.0 || acosValue < -1.0) {
            return IKResult("IK solution out of range!");
        }

        angle = atan2(pz, py) + ((pz < 0) ? acos(acosValue) : -acos(acosValue));
        angle = angle * 180.0 / M_PI;  // Convert to degrees
        servoAngles[i] = angle;
    }

    return IKResult(servoAngles);  // Return successful result
}

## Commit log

2025-02-12 initial commit AP working with buttons to move robot between 2 poses
2025-02-12 Implement trajectory generation and smooth pose transitions
    - Added Trajectory class to generate smooth, time-scaled motion between poses
    - Replaced simple acceleration capping with trajectory following
    - Updated Controller to use trajectory for goal pose movements
    - Added magnitude calculation to Pose class
    - Modified update loop to follow trajectory before solving inverse kinematics
    [controller.cpp, stewy.ino]
2025-02-18 created individual components of web interface and added python tool for adding it to the arduino file
2025-03-23 Added CAD files
    [Stewy Arm Left.step, Stewy Arm Right.step, Stewy Base Bottom.step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]
2025-10-29 joystick velocity controll working
2025-10-30 Solved IK to set boundaries for the joystick velocity control
    [controller.cpp]
2025-10-30 fixed joystick velocity control directions and some small bugs
    [controller.cpp]
2025-11-01 implemented collision avoidance based on distance sensor
    [controller.cpp, stewy.ino]
2025-11-01 minor collision avoidance bug
    [controller.cpp]
2026-02-09 added home position where arms touch the ground
